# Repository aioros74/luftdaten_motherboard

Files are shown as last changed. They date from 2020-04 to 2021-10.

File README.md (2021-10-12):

# Luftdaten motherboard
## Description
### French version
La carte support luftdaten v1r1 est un circuit imprimé destiné à simplifier et apporter plus d’options au montage du détecteur de particules fines du projet Sensor Community (https://sensor.community/fr/). La page du montage: https://sensor.community/fr/sensors/airrohr/

Cette carte permet :
* D’exposer les IOs de l’ESP8266 sur des connecteurs.
* De fixer l’ESP8266 et les détecteurs de particules fines SDS011 et PMS7003 sur une même carte, et évite les câblages volants.
* D’utiliser le câble fourni avec le SDS011.
* Différentes options d’alimentation :
  * Câble USB.
  * Alimentation externe directe.
  * Alimentation externe avec régulateurs DC/DC.

### English version

The luftdaten v1r1 motherboard is a printed circuit intended to simplify and provide more options for mounting the particule matter sensors of the Sensor Community project (https://sensor.community/en/). Link to the hardware: https://sensor.community/fr/sensors/airrohr/

This card allows:
* Access to ESP8266 I/0
* To fix the ESP8266 and the particule matter sensors SDS011 and PMS7003 on the same card, and avoid flying cables.
* Use the cable provided with the SDS011.
* Several power supply options:
	* USB cable.
	* External direct power supply.
	* External power supply with DC/DC regulators.

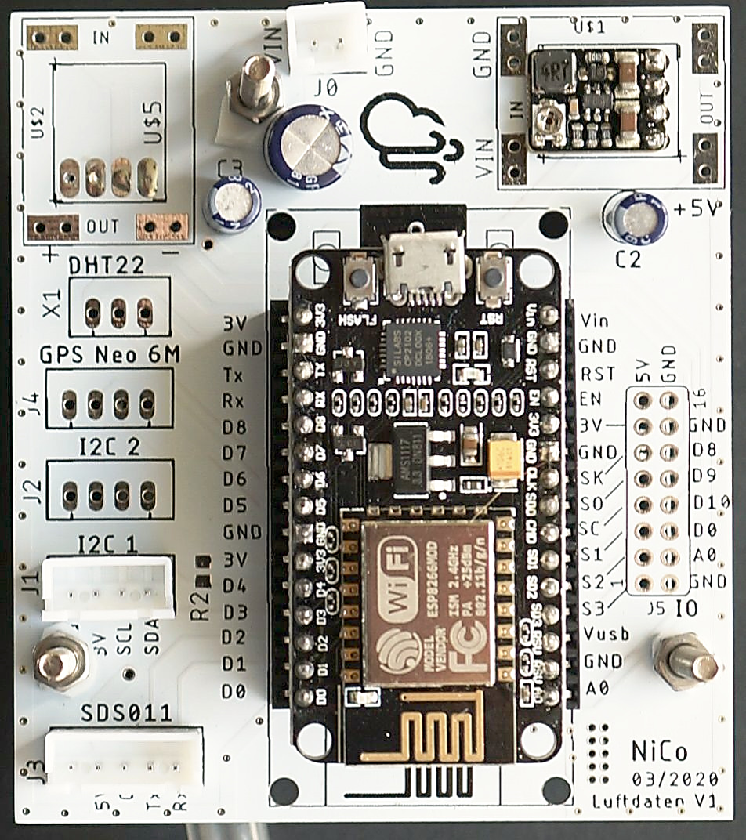
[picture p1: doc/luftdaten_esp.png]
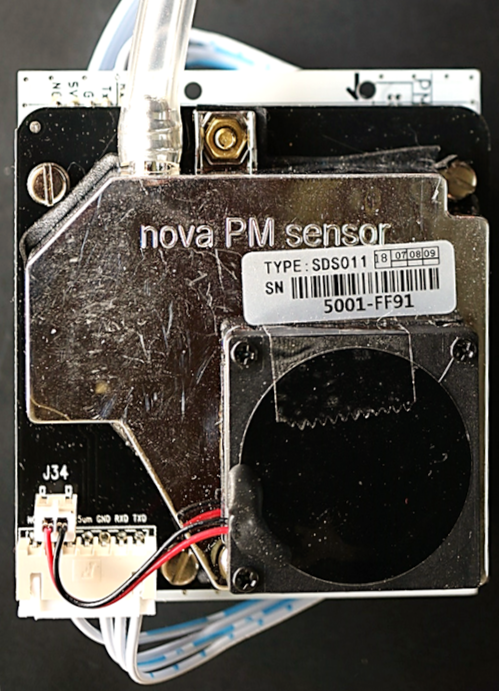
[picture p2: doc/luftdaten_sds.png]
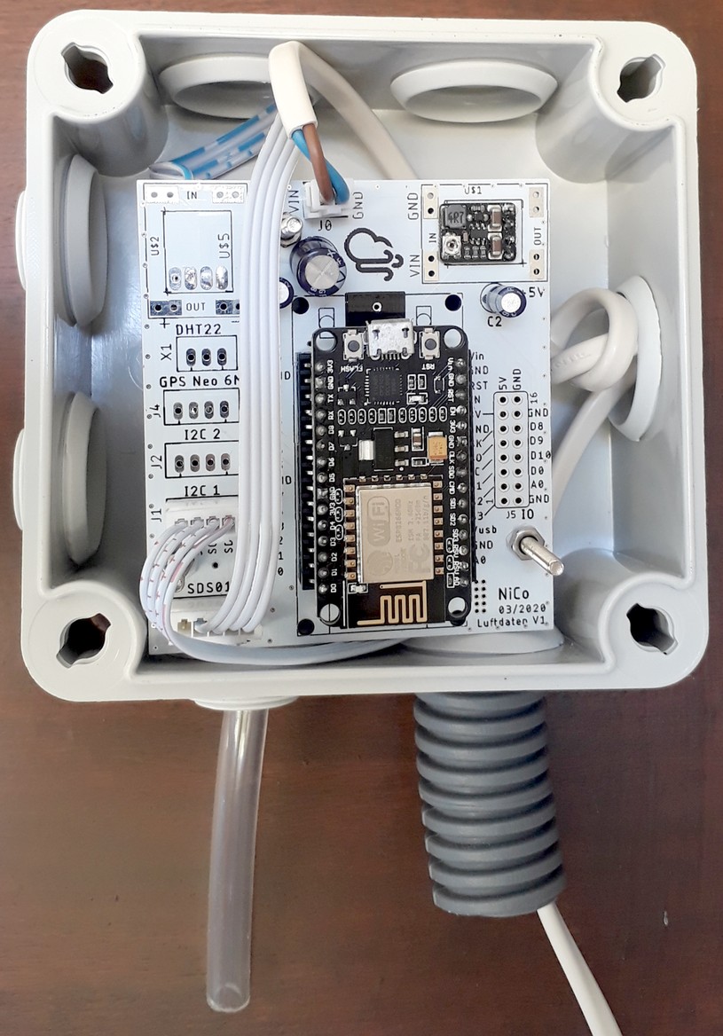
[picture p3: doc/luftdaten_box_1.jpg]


## Documentation
* Documentation de la carte: [documentation](./doc/Carte%20Support%20Luftdaten%20v1r1.pdf)
* Schéma de la carte: [schéma](./doc/schematic_uftdaten_v1r1.pdf)
* CAO Eagle: [CAO](./cao/)
* Fichiers de fabrication: [gerbers](./manufacturing/)
* Photos du PCB

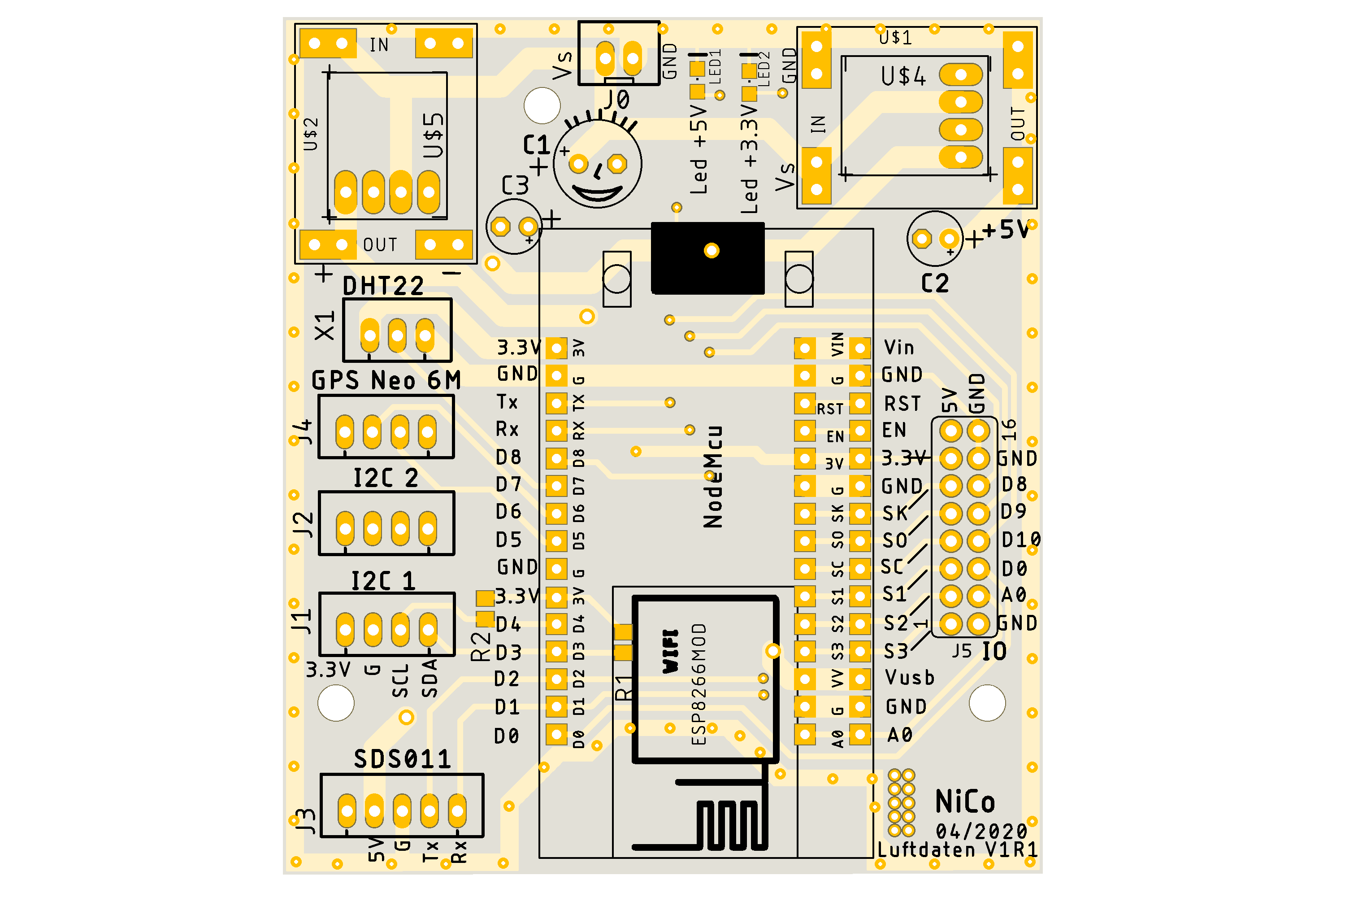
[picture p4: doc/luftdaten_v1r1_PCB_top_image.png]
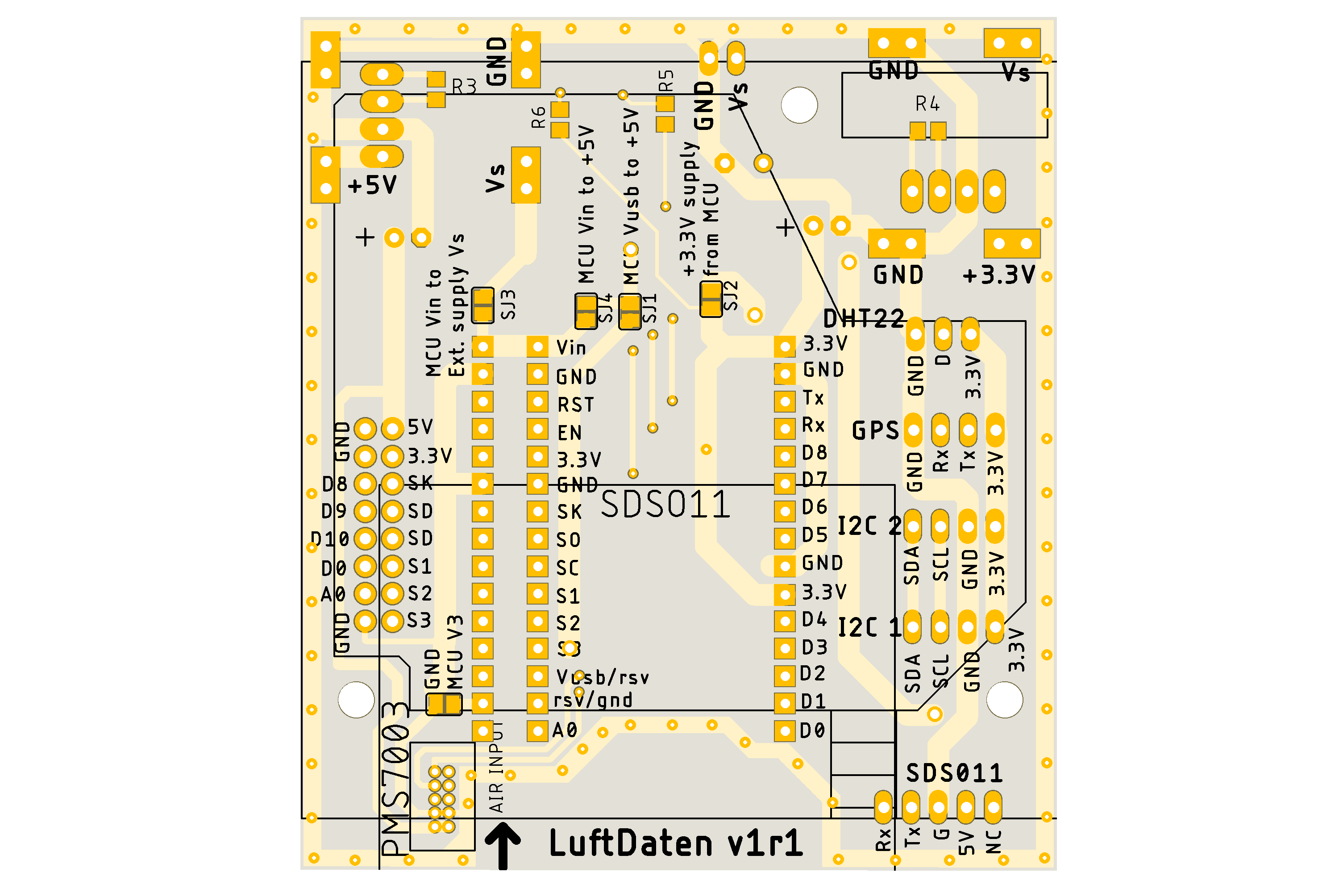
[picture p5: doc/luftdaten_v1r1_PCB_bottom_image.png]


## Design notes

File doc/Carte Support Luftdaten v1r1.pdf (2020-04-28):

# Carte Support Luftdaten

v1r1

## Nicolas Letendre

28/04/2020

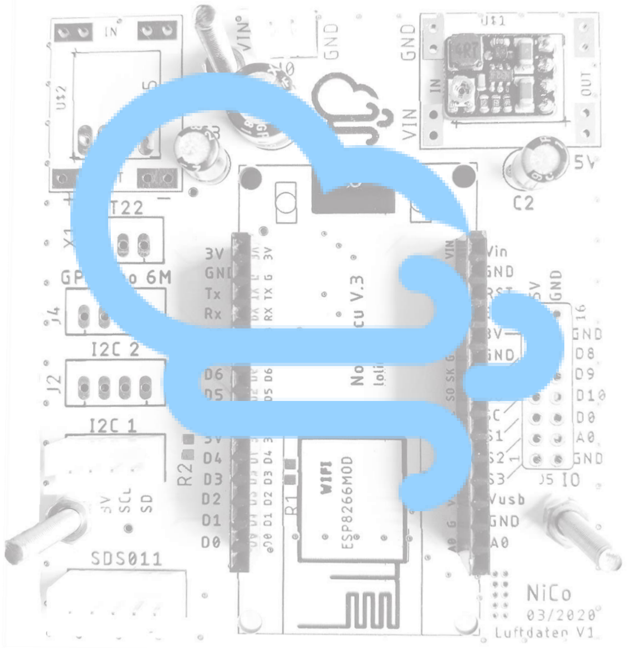
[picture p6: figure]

### Table des matières

## 1 Description

La carte support luftdaten v1r1 est un circuit imprimé destiné à simplifier et apporter plus
d’options | au | montage | du | détecteur de | particules | fines | du | projet | Luftdaten
(https://luftdaten.info/fr/accueil/).
Cette carte permet :
- D’exposer les IOs de l’ESP8266 sur des connecteurs.
- De fixer l’ESP8266 et les détecteurs de particules fines SDS011 et PMS7003 sur une même carte, et évite les câblages volants.
- D’utiliser le câble fourni avec le SDS011.
- Différentes options d’alimentation :
- Câble USB.
- Alimentation externe directe.
- Alimentation externe avec régulateurs DC/DC.

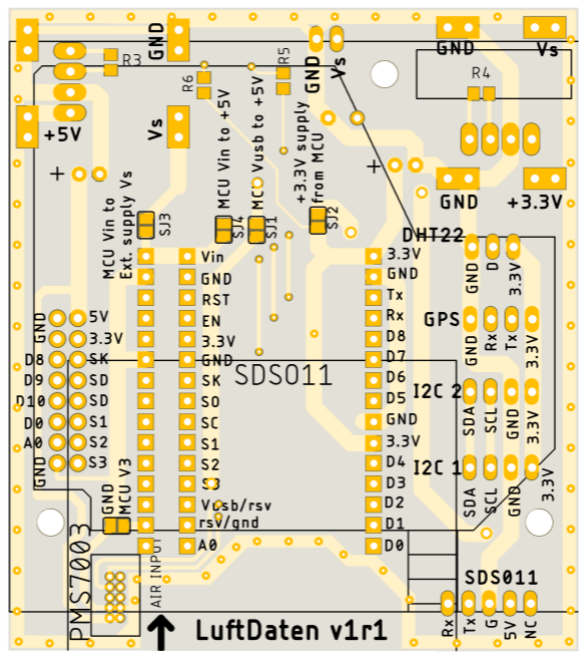
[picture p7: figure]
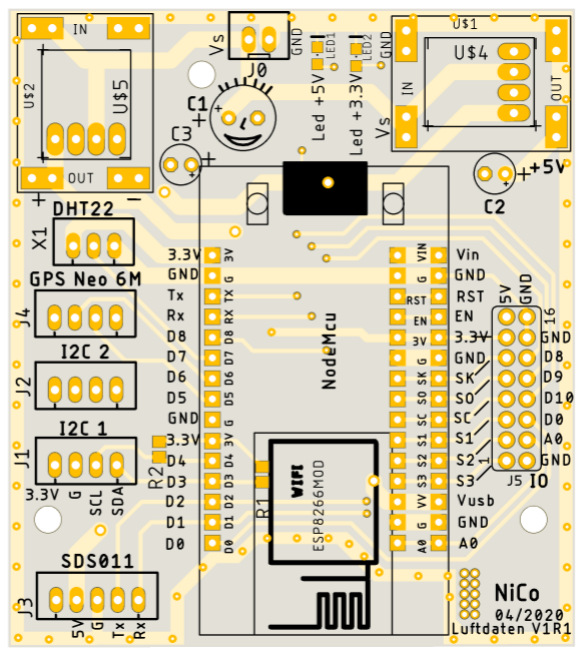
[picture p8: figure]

Figure 1: Vue de la carte support. A gauche vue de dessus, à droite vue de dessous.

## 2 Connectique

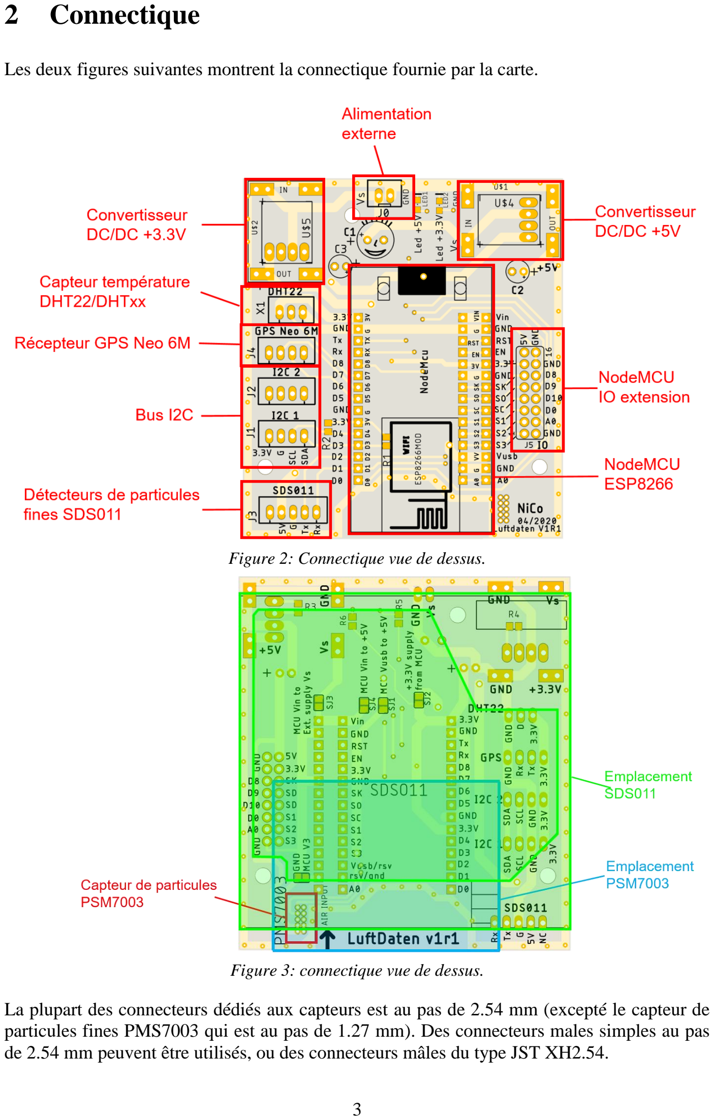
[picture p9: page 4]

Les deux figures suivantes montrent la connectique fournie par la carte.

Figure 2: Connectique vue de dessus.

Figure 3: connectique vue de dessus.

La plupart des connecteurs dédiés aux capteurs est au pas de 2.54 mm (excepté le capteur de particules fines PMS7003 qui est au pas de 1.27 mm). Des connecteurs males simples au pas de 2.54 mm peuvent être utilisés, ou des connecteurs mâles du type JST XH2.54.

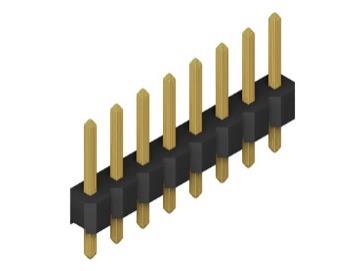
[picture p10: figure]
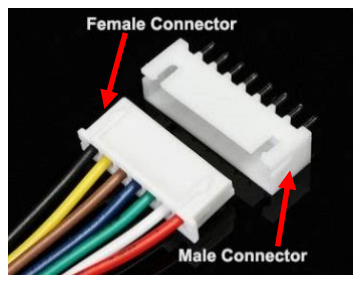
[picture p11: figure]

Broches au pas de 2.54 mm | Connecteurs JST XH2.54

### 2.1 NodeMCU ESP8266

Le cœur du montage est la carte NodeMCU V3, basée sur un contrôleur ESP8266. Deux types de NodeMCU V3 existent sur le marché :

- Une version avec un contrôleur USB CH340.
- Une version un peu moins large basée sur le contrôleur USB CP2102.

La carte support accepte les deux types de contrôleurs.

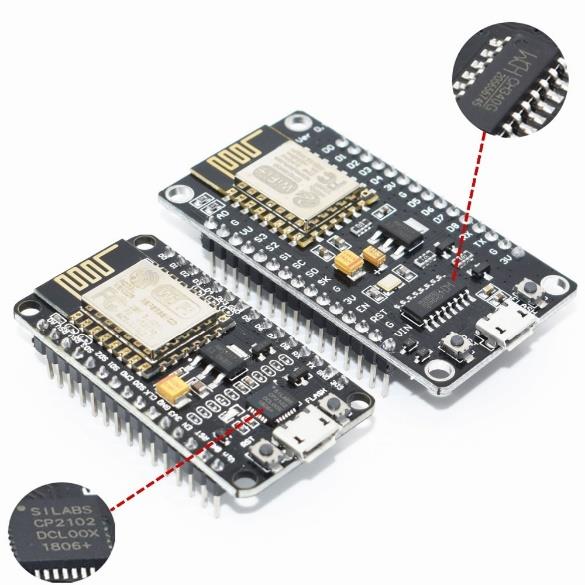
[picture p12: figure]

Figure 4: NodeMCU V3. A gauche basée sur un contrôleur CP2102 à droite sur le contrôleur CH340.

Sur la carte support, le pas des connecteurs pour le NodeMCU est de 2.54 mm. L’écart entre les deux rangées est de 22.86 mm pour la version CP2102 et de 27.94 mm pour la version CH340.

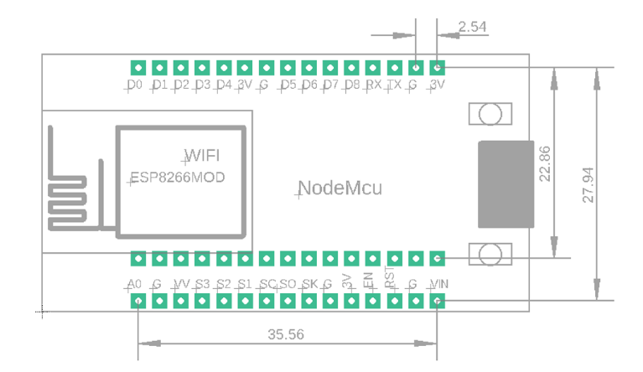
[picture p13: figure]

Figure 5: Dimension des broches du NodeMCU.

Le NodeMCU peut être soit soudé directement sur la carte support, ou soit inséré sur des supports femelles au pas de 2.54 mm soudés sur la carte. (Deux supports 1x15 au pas de 2.54 mm)

Figure 6: support femelle 1x15 au pas de 2.54 mm

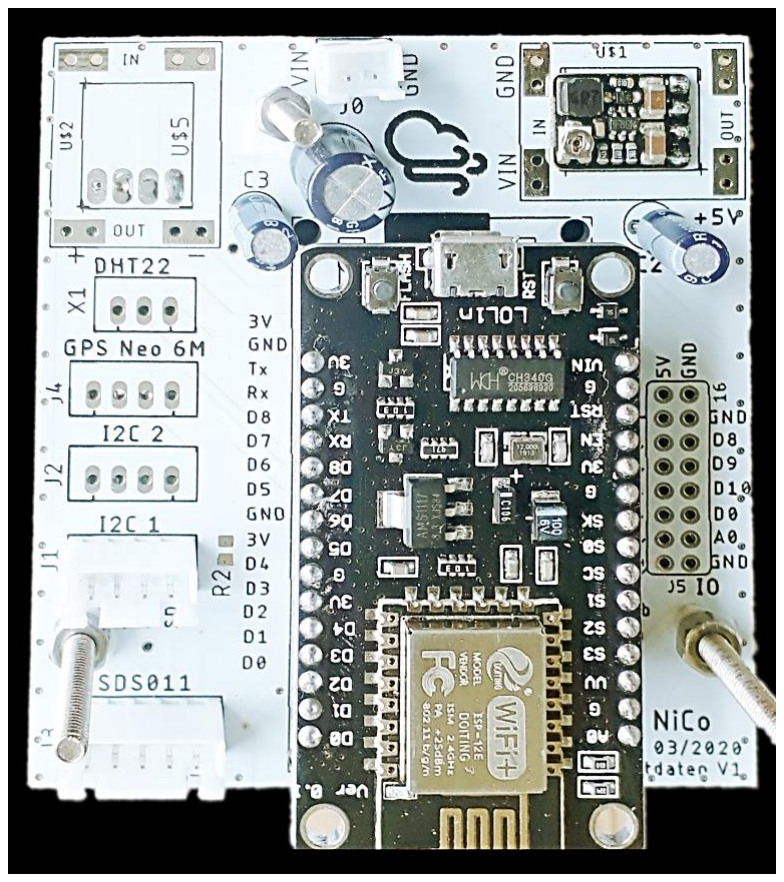
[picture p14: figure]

Figure 7 : vue de la carte support avec le NodeMCU.

### 2.2 Capteur SDS011

La carte support accepte le capteur de particules fine SDS011 de Inovafitness. Ce capteur se monte sur la face « dessous » de la carte support.
ATTENTION : Le capteur ne doit pas toucher le circuit imprimé pour ne pas mettre en court-circuit les broches du NodeMCU soudé sur l’autre face. Il est donc conseillé de monter le SDS011 avec des entretoises, ou d’insérer un isolant (plastique ou autre) entre le SDS011 et le circuit imprimé.

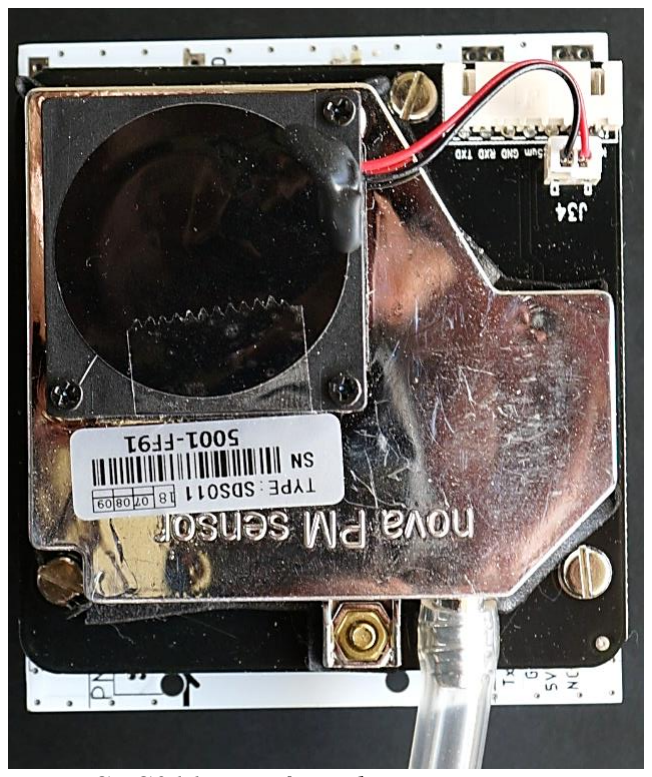
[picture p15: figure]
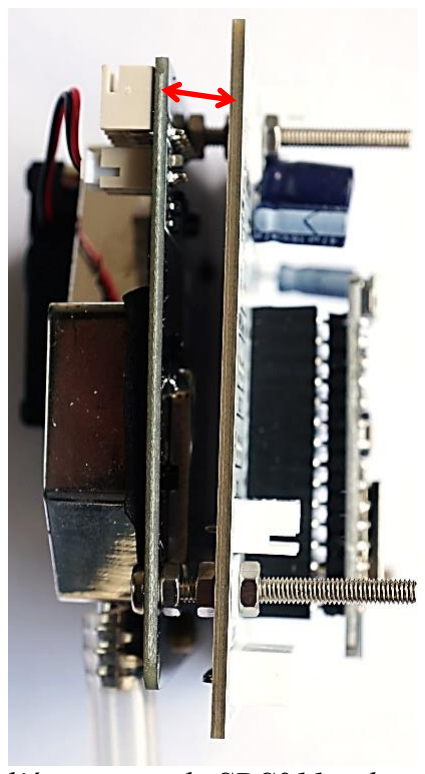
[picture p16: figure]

Figure 8 : SDS011 monté sur la carte support. Notez l’écart entre le SDS011 et la carte.

Le SDS011 se connecte sur le connecteur J3 sur la face « dessus » de la carte support avec la nappe de fils livrée avec le SDS011. Sur la carte support les broches du capteur de particules fines sont reliées au NodeMCU comme indiqué dans le tableau suivant :

SDS011 | Connecteur carte support
Pin 3 : 5V | 5V
Pin 5 : GND | GND
Pin 6 : R | Tx – NodeMCU pin D2
Pin 7 : T | Rx – NodeMCU pin D1
Table 1 : Table de correspondances entre les broches du SDS011 et la carte support.

### 2.3 Capteur PMS7003

Le capteur de particules fines PMS7003 est un autre capteur qui peut être monté directement sur la carte support. Le capteur se monte sur la face « dessous » de la carte support. Il est nécessaire de souder la connecteur 2x5 (2 rangées de 5 broches) au pas de 1.27mm. Ce connecteur est parfois vendu avec le PMS7003.
ATTENTION : Le PMS7003 doit être fixé sur la carte support avec du scotch double face par exemple. Ce double face joue aussi le rôle d’isolant électrique entre le circuit imprimé et le capteur, notamment si la pellicule de protection bleue du PSM7003 a été retirés. Le capot du PMS7003 étant métallique, il pourrait provoquer des court-circuits sur la carte support. De plus, il est nécessaire de souder le NodeMCU sans que les broches dépassent sur la face « dessous » de la carte support.

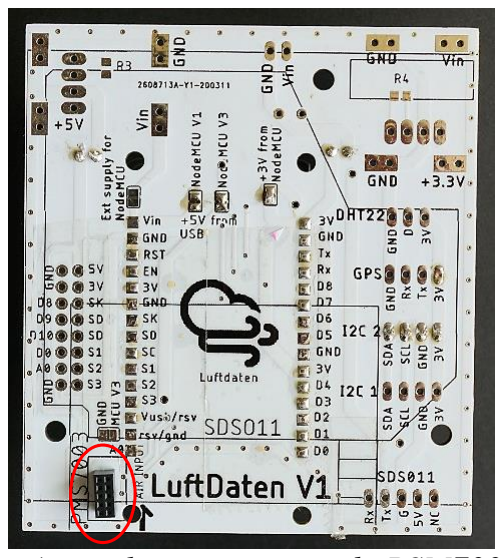
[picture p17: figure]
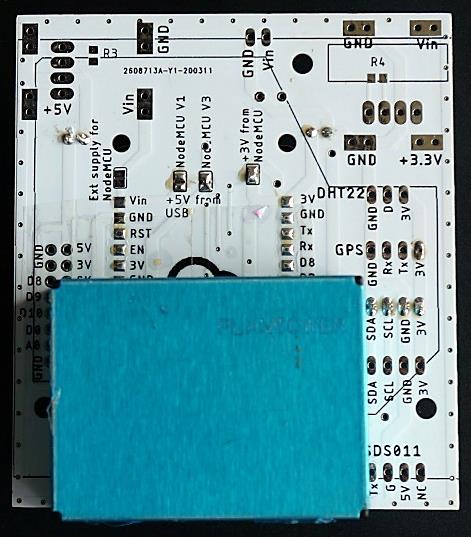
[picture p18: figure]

Figure 9 : A gauche : connecteur du PSM7003 soudé sur la carte. A droite : capteur monté.

PMS7003 | Node MCU
Pin 1 : 5V | +5V
Pin 2 : 5V | +5V
Pin 3 : GND | GND
Pin 4 : GND | GND
Pin 5 : Reset | NC
Pin 6 : NC (Not Connected) | NC
Pin 7 : RX | D2
Pin 8 : NC | NC
Pin 9 : TX | D1
Pin 10 : Set | NC
Table 2 : Table de correspondance entre les broches du PMS7003 et la carte support.

### 2.4 Capteur de température et d’humidité DHT22

Le capteur de température DHT22 se branche sur le connecteur X1.

DHT22 | Carte support

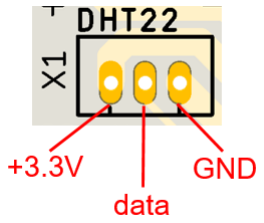
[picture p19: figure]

Pin 1 : VCC | +3.3V
Pin 2 : DATA | D – NodeMCU pin D7
Pin 3 : NC | -
Pin 4 : GND | GND
Table 3 : Table de correspondance entre les broches du DHT22 et la carte support.

### 2.5 GPS Neo-6m

Un récepteur GPS de type Neo-6m peut être connecté à la carte support sur le connecteur J4. Le récepteur Neo-6m est généralement vendu sous forme de module. Ce module communique avec le NodeMCU à travers une liaison série.

Module Neo-6m | Carte support connecteur J4

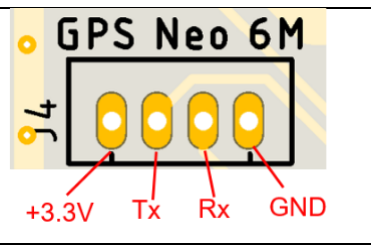
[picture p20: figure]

Pin VCC | +3.3V
Pin RX | Tx – Node MCU pin D6
Pin TX | Rx è Node MCU pin D5
Pin GND | GND

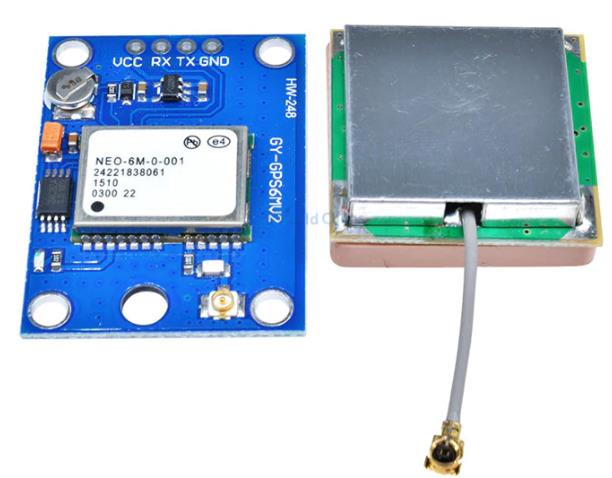
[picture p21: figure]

Table 4: Table de correspondance entre les broches du module Neo-6m et la carte support.

### 2.6 I2C

La carte support possède deux connecteurs I2C nommés J1 et J2. Le projet Luftdaten prend en compte un certain nombre de modules I2C dont voici une liste non exhaustive :

- Capteurs de température et d’humidité : BME280 / HTU21D / SHT3x.
- Capteurs de température et de pression : BMP180.
- Capteur de température, humidité, pression : BMP280.
- Ecrans OLED basés sur le contrôleur SH1106 ou SSD1306.

Les broches I2C (SDA et SCL) sont reliées aux broches D3 et D4 du NodeMCU.

Carte support J1 et J2

+3.3V
GND
SCL – NodeMCU pin D4
SDA – NodeMCU pin D3
Table 5 : Brochage des connecteurs I2C.

Les résistance R1 et R2 permettent d’ajouter des résistances de tirage (pull-up) externes sur les lignes du bus I2C (SDA et SCL).

### 2.7 NodeMCU I/O

Le connecteur J5 permet un accès à toutes les broches du NodeMCU non utilisées pas les autres connecteurs. Le tableau suivant montre le brochage du connecteur J5.

Carte support J5

Pin 1 : NodeMCU pin S3 | Pin 2 : GND
Pin 3 : NodeMCU pin S2 | Pin 4 : NodeMCU pin A0
Pin 5 : NodeMCU pin S1 | Pin 6 : NodeMCU pin D0
Pin 7 : NodeMCU pin SC | Pin 8 : NodeMCU pin D10
Pin 9 : NodeMCU pin SD | Pin 10 : NodeMCU pin D9
Pin 11 : NodeMCU pin SK | Pin 12 : NodeMCU pin D10
Pin 13 :+3.3V | Pin 14 : GND
Pin 15 :+5V | Pin 16 : GND
Table 6 : Brochage du connecteur d’extension des I0s du NodeMCU.

## 3 Alimentation

Pour fonctionner le système à besoins d’une alimentation +3.3V pour le NodeMCU et certains capteurs, et d’une alimentation +5V pour les capteurs de particules fines.
La carte support offre plusieurs possibilités pour fournir ces alimentations. Des ponts de soudure permettent de sélectionner un profil d’alimentation parmi les différentes options.

### 3.1 Alimenter le NodeMCU V3

La figure suivante montre le schéma de l’alimentation du NodeMCU V3.

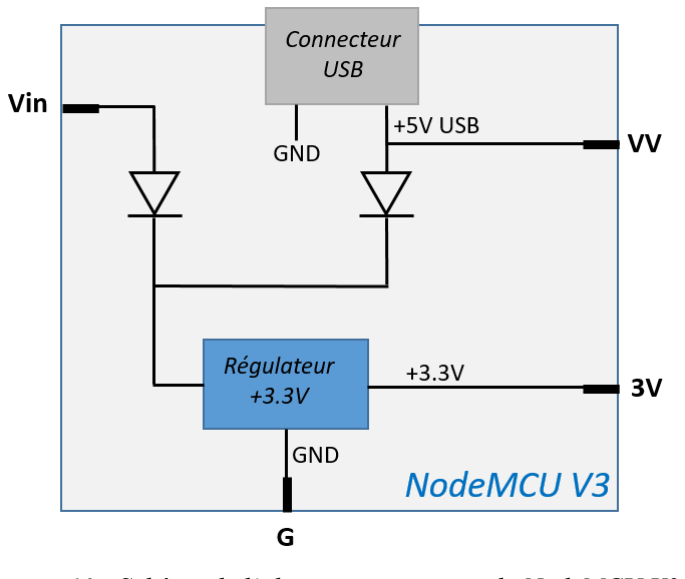
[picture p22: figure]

Figure 10 : Schéma de l’alimentation interne du NodeMCU V3.

Il y a 3 façons d’alimenter le nodeMCU :

1. Par le connecteur USB. Le bus USB fourni une alimentation de +5V. Le régulateur linéaire AMS1117-3.3 se charge alors de convertir ce +5V en +3.3V. Le NodeMCU fourni donc le +5V sur sa broche VV, et le +3.3V sur sa broche 3V.
2. Par la broche Vin. La tension sur la broche Vin doit être comprise entre +4.8V (= 3.3V+Vdrop+Vdiode = 3.3+1.3+0.2) et +15V. Dans cette configuration, le NodeMCU fourni le +3.3V sur sa broche 3V. Par contre, il ne produit pas de +5V.
3. Par la broche 3.3V. Dans cette configuration, le NodeMCU est alimenté directement par un +3.3V externe appliqué sur la broche 3V. Le nodeMCU ne fournit pas de +5V.

### 3.2 Les options d’alimentation de la carte support

### 3.2.1 Le connecteur d’alimentation

La carte support possède un connecteur d’alimentation J0 qui permet de brancher une alimentation externe. Ce connecteur doit être au pas de 2.54 mm. Il y a la possibilité d’ajouter un condensateur C1 pour filtrer l’alimentation.

### 3.2.2 Convertisseurs DC/DC

La carte support possède deux emplacements pour des convertisseurs DC/DC ; un pour produire une tension de +5V, et l’autre pour le +3.3V. Un régulateur DC/DC possède un rendement supérieur à un régulateur linéaire. Il peut y avoir plusieurs raisons d’utiliser un régulateur DC/DC :

- Augmenter la plage d’alimentation du montage jusqu’à +28V, et donc utiliser n’importe quelle « bloc mural » AC/DC. Si la connexion entre le bloc mural et le montage Luftdaten, il peut y avoir une perte de tension dans les longs fils. Alimenter le montage avec une tension plus élevée puis régulée avec une convertisseur DC/DC supprime cet inconvénient.
- Améliorer le rendement de conversion.

Deux régulateurs DC/DC peuvent être utilisés sur la carte support :

Module basé sur le MP1584 | Module BB2359

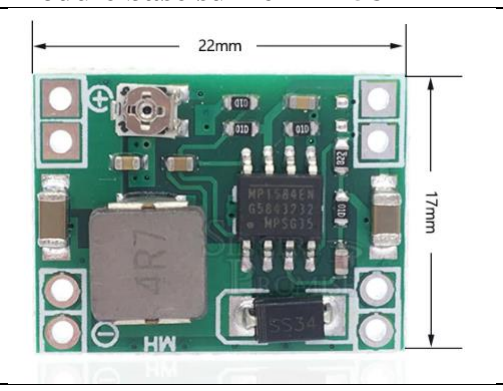
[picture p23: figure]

régulateur | MP1584EN | MP2359
Tension d’entrée | +4.5V à +28V | +4.5V à +24V
Tension de sortie | +0.8V à +25V | +0.81V à +15V
Courant max | 3A | 1.2A
Table 7 : Les deux régulateurs DC/DC utilisables sur la carte support.

### 3.2.3 Schéma d’alimentation de la carte support

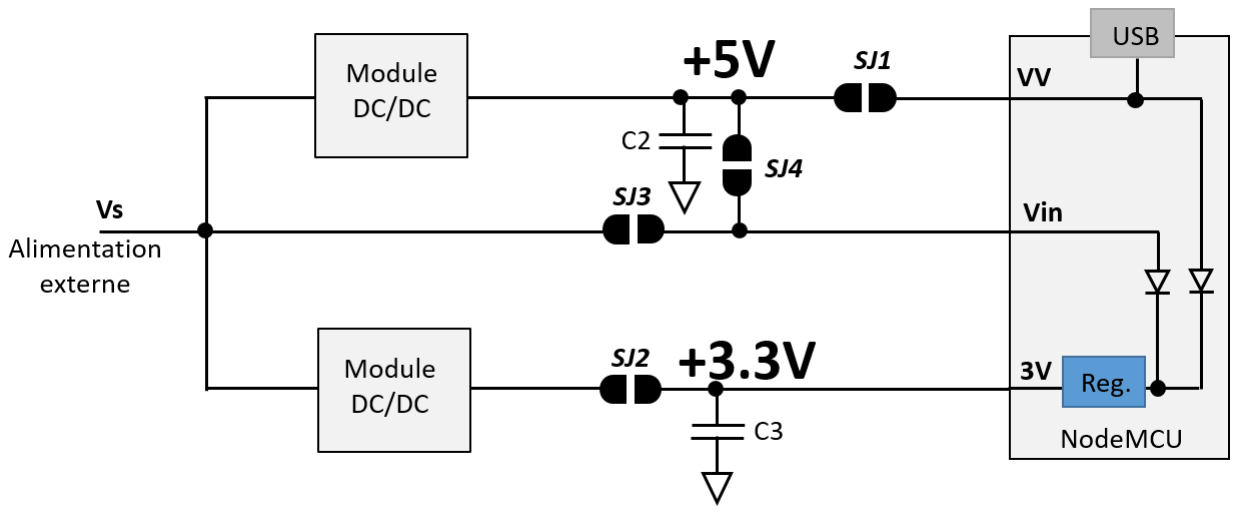
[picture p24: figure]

Figure 11 : Schéma général des alimentations sur la carte support.

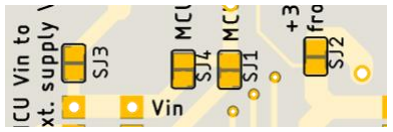
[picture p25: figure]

Figure 12: Ponts SJ1 à SJ4.

Quatre ponts (SJ1 à SJ4) permettent de choisir l’option d’alimentation. Une goutte de soudure sur le pont permet de réaliser la connexion. Les condensateurs C2 et C3 permettent de filtrer les rails
d’alimentation | (resp. | +5V | et | +3.3V). | Ces
condensateurs ne sont pas obligatoires.

Alimentation par l’USB

Le montage peut être alimenté directement par le connecteur USB du NodeMCU. Le tableau suivant montre la configuration nécessaire. Une croix signifie que le pont doit être soudé.

Dans cette configuration, les régulateurs DC/DC ne sont pas câblés et l’alimentation externe n’est pas utilisée.

SJ1 | X

SJ2

SJ3

SJ4

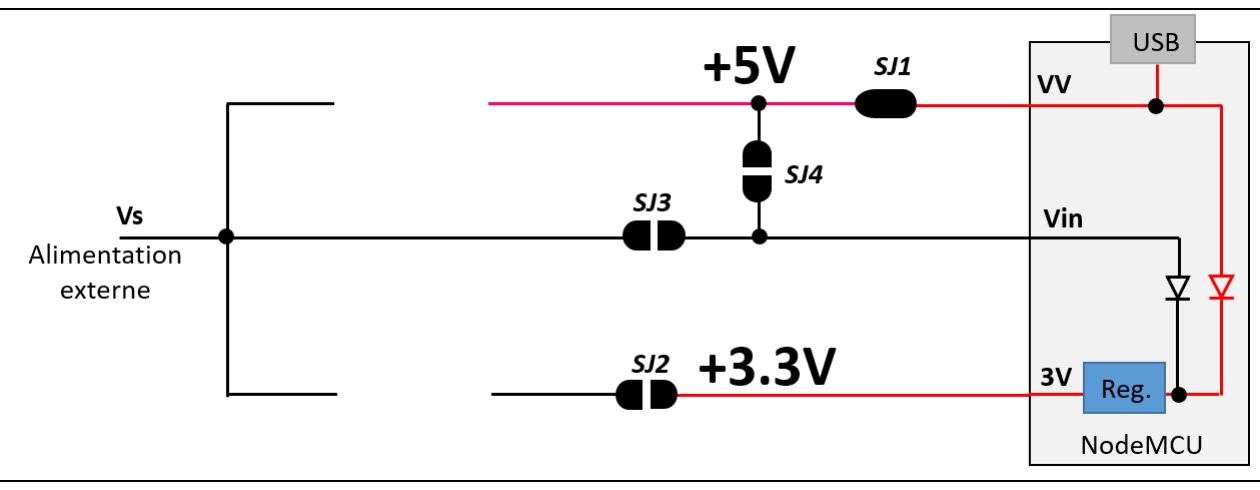
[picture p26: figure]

Figure 13 : Configuration pour une alimentation par câble USB.

Alimentation externe +5V

Le montage est alimenté par une alimentation externe +5V. Les convertisseurs DC/DC ne sont pas utilisés.

SJ1

SJ2

SJ3 | X
SJ4 | X

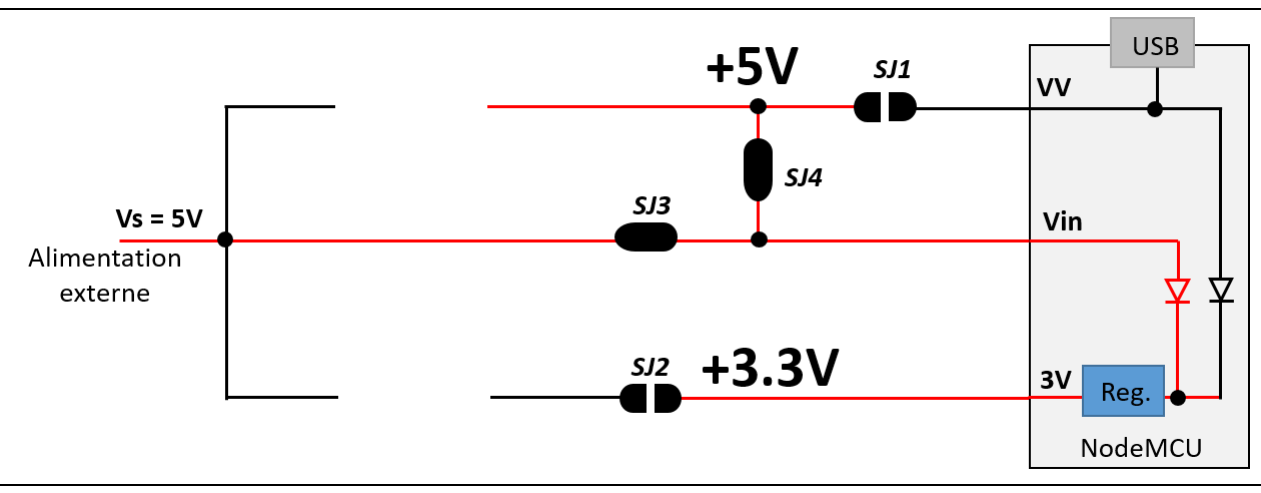
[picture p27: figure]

Figure 14 : Configuration pour une alimentation par un +5V externe.

Alimentation externe >5V – régulateur DC/DC +5V

Dans cette configuration, le montage est alimenté par une alimentation externe supérieure à 5V. Le +5V est fourni par le convertisseur DC/DC, et le +3.3V par le nodeMCU.

SJ1

SJ2

SJ3

SJ4 | X

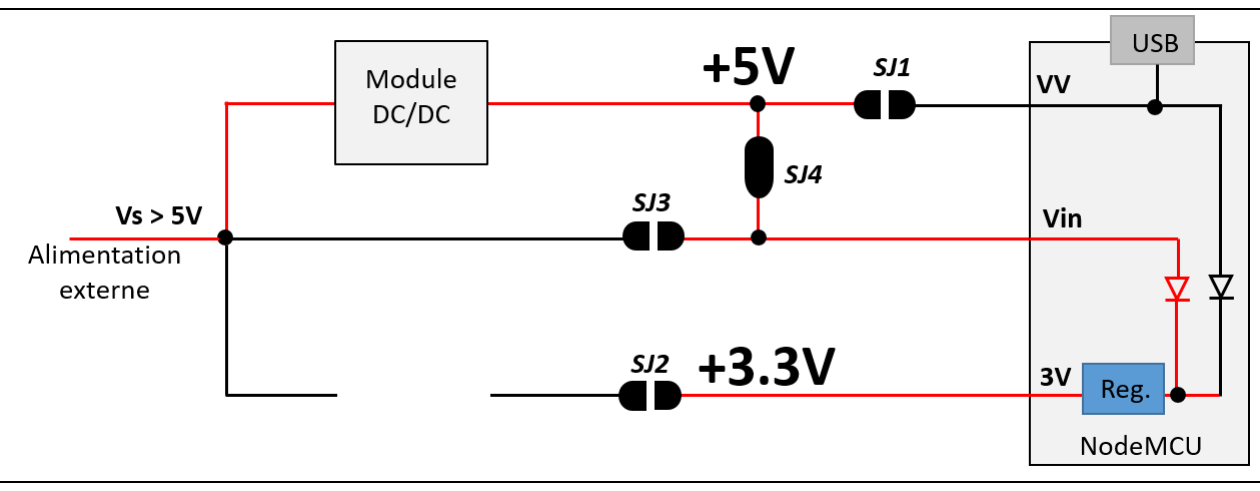
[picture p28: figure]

Figure 15 : Configuration pour une alimentation par une tension externe supérieure à 5V.

Alimentation externe >5V – régulateurs DC/DC +5V et +3.3V

Dans cette configuration, le montage est alimenté par une alimentation externe supérieure à 5V. Le +5V est fourni par le convertisseur DC/DC, et le +3.3V par le second régulateur DC/DC.

SJ1

SJ2 | X

SJ3

SJ4

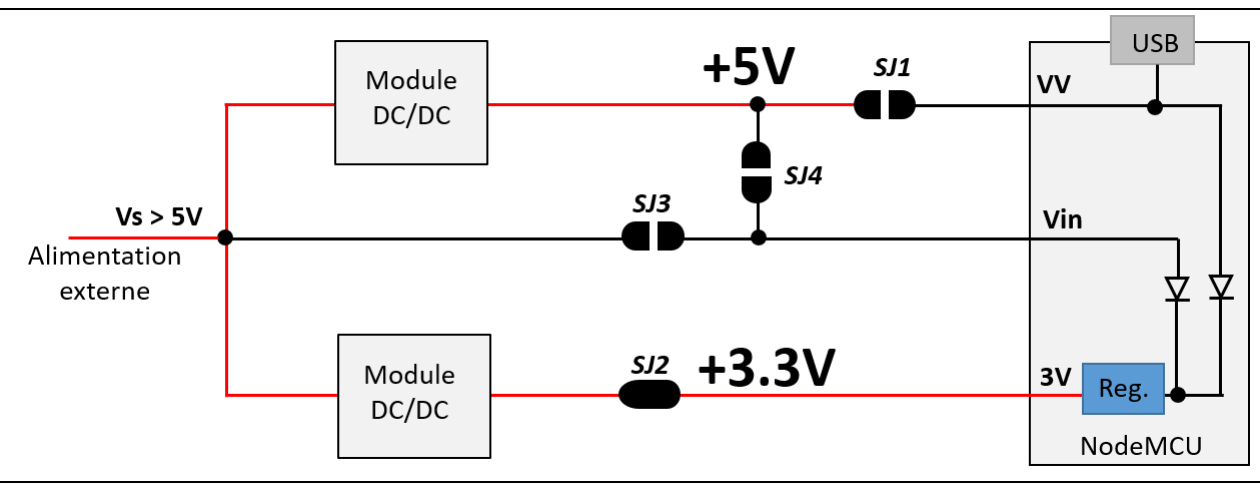
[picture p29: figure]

Figure 16 : Configuration pour une alimentation par une tension externe supérieure à 5V.

### 3.2.4 Leds

Il est possible de câbler des leds sur les rails d’alimentation +5V et +3.3V. Ces leds ainsi que les résistances associées sont en format de boitier 0805.

- Pour la led +5V : cabler la led L1 et la résistance R5.
- Pour la led +3.3V : cabler la led L2 et la résistance R6.

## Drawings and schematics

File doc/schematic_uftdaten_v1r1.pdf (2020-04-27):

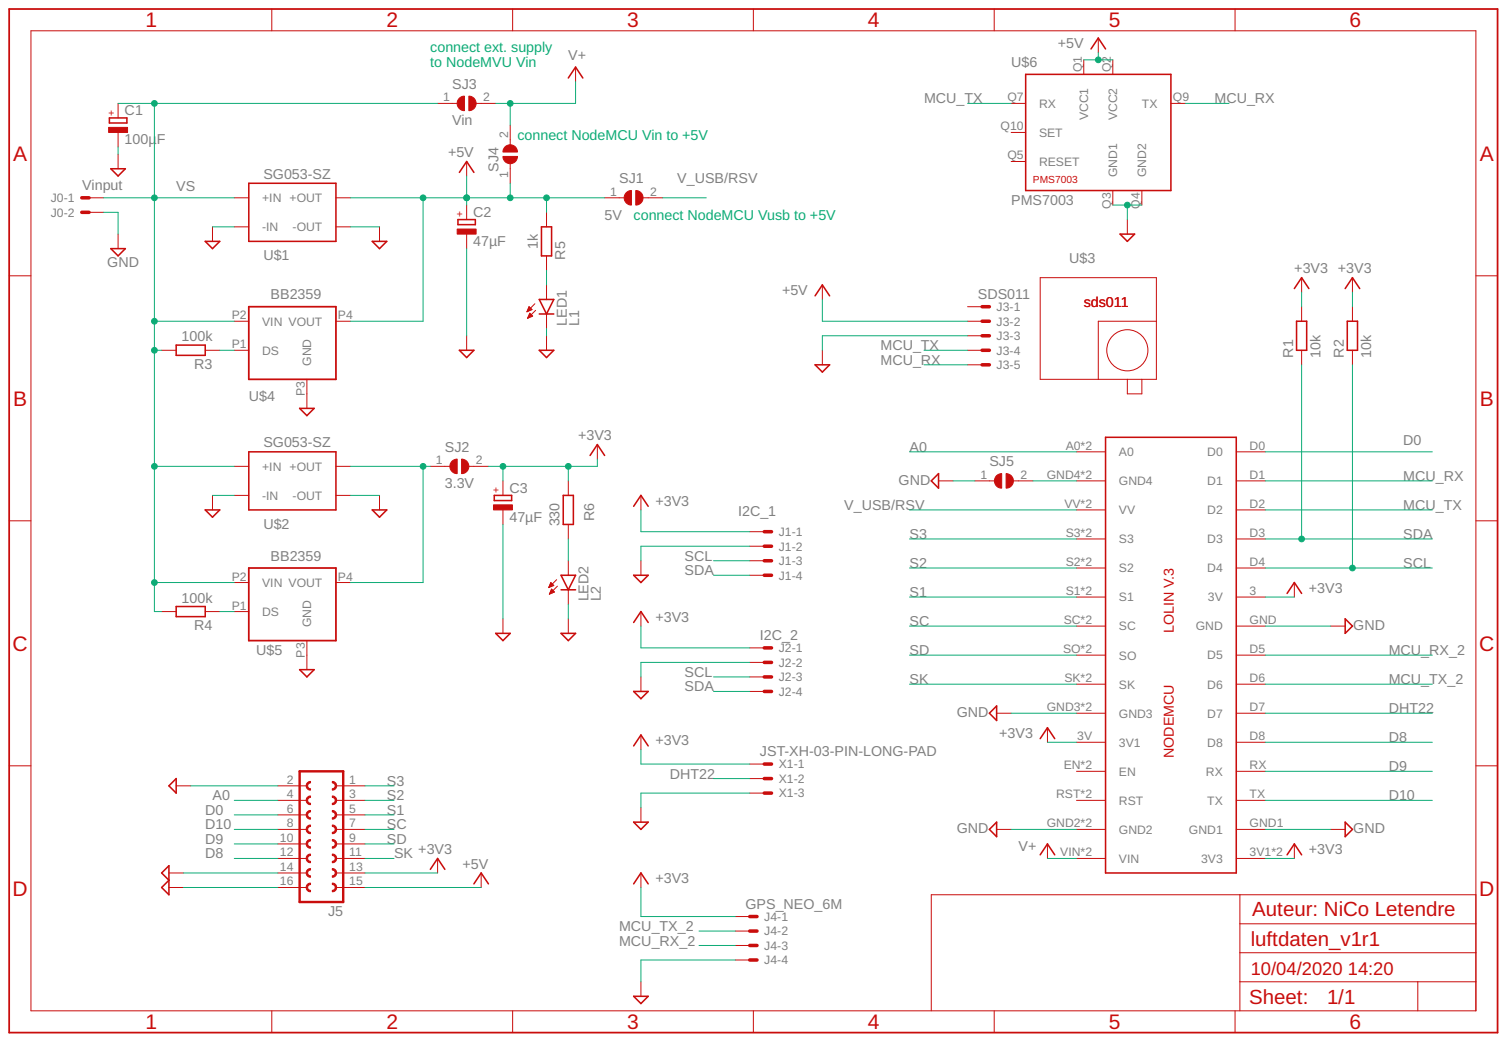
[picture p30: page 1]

connect NodeMCU Vin to +5V

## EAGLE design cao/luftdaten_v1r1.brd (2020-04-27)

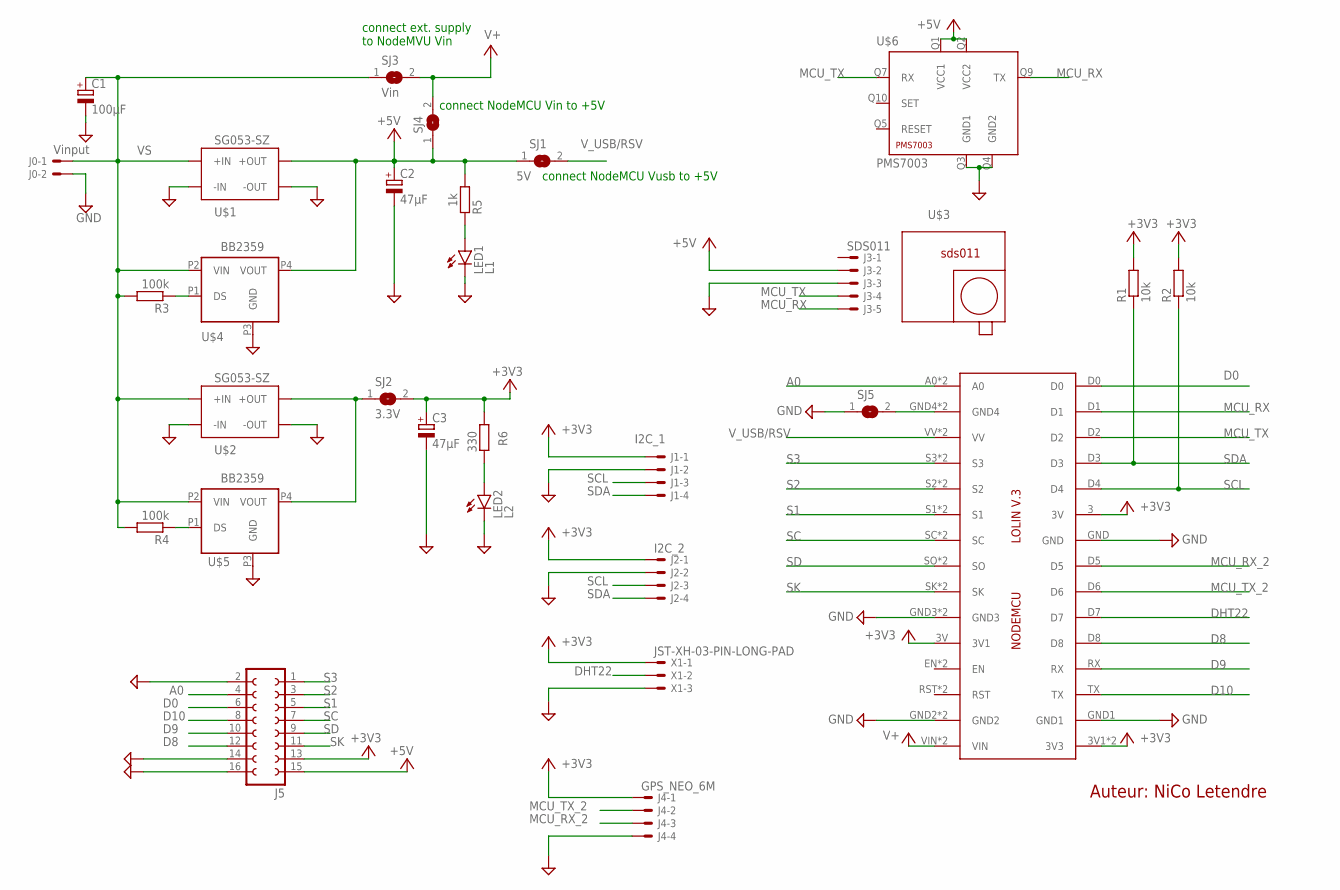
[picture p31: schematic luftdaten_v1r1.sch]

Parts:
C1: 100µF; E3,5-8
C2, C3: 47µF; E2,5-5
IC2: NodeMCU; LOLINV3
J0: Vinput; JST-XH-02-PACKAGE-LONG-PAD
J1: I2C_1; JST-XH-04-PACKAGE-LONG-PAD
J2: I2C_2; JST-XH-04-PACKAGE-LONG-PAD
J3: SDS011; JST-XH-05-PACKAGE-LONG-PAD
J4: GPS_NEO_6M; JST-XH-04-PACKAGE-LONG-PAD
J5: FE08-2
LED1: L1; CHIPLED_0805
LED2: L2; CHIPLED_0805
R1, R2: 10k; R0805
R3, R4: 100k; R0805
R5: 1k; R0805
R6: 330; R0805
SJ1: 5V; SJ
SJ2: 3.3V; SJ
SJ3: Vin; SJ
SJ4, SJ5: SJ
U$1, U$2: SG053-SZ
U$3: SDSO11; SDS011
U$4, U$5: BB2359
U$6: PMS7003
X1: JST-XH-03-PIN-LONG-PAD; JST-XH-03-PACKAGE-LONG-PAD

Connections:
+3V3: C3.+, IC2.3 (3V), IC2.3V (3V1), IC2.3V1 (3V3), IC2.3V3, J1.1, J2.1, J4.1, J5.13, R1.2, R2.2, R6.1, SJ2.2, X1.1
+5V: C2.+, J3.2, J5.15, R5.1, SJ1.1, SJ4.1, U$1.P$5 (+OUT), U$1.P$6 (+OUT), U$4.P4 (VOUT), U$6.Q1 (VCC1), U$6.Q2 (VCC2)
A0: IC2.A0, IC2.A1 (A0), J5.4
D0: IC2.D0, J5.6
D8: IC2.D8, J5.12
D9: IC2.RX, J5.10
D10: IC2.TX, J5.8
DHT22: IC2.D7, X1.2
GND: C1.-, C2.-, C3.-, IC2.GND, IC2.GND1, IC2.GND2, IC2.GND3, IC2.GND5 (GND2), IC2.GND6 (GND3), J0.2, J1.2, J2.2, J3.3, J4.4, J5.2, J5.14, J5.16, LED1.C, LED2.C, SJ5.1, U$1.P$1 (-IN), U$1.P$2 (-IN), U$1.P$7 (-OUT), U$1.P$8 (-OUT), U$2.P$1 (-IN), U$2.P$2 (-IN), U$2.P$7 (-OUT), U$2.P$8 (-OUT), U$4.P3 (GND), U$5.P3 (GND), U$6.Q3 (GND1), U$6.Q4 (GND2), X1.3
MCU_RX: IC2.D1, J3.5, U$6.Q9 (TX)
MCU_RX_2: IC2.D5, J4.3
MCU_TX: IC2.D2, J3.4, U$6.Q7 (RX)
MCU_TX_2: IC2.D6, J4.2
unnamed: IC2.GND4, IC2.GND7 (GND4), SJ5.2
unnamed: SJ2.1, U$2.P$5 (+OUT), U$2.P$6 (+OUT), U$5.P4 (VOUT)
unnamed: R3.1, U$4.P1 (DS)
unnamed: R4.1, U$5.P1 (DS)
unnamed: LED1.A, R5.2
unnamed: LED2.A, R6.2
S1: IC2.S1, IC2.S4 (S1), J5.5
S2: IC2.S2, IC2.S5 (S2), J5.3
S3: IC2.S3, IC2.S6 (S3), J5.1
SC: IC2.SC, IC2.SC1 (SC), J5.7
SCL: IC2.D4, J1.3, J2.3, R2.1
SD: IC2.SO, IC2.SO1 (SO), J5.9
SDA: IC2.D3, J1.4, J2.4, R1.1
SK: IC2.SK, IC2.SK1 (SK), J5.11
V+: IC2.VIN, IC2.VIN1 (VIN), SJ3.2, SJ4.2
VS: C1.+, J0.1, R3.2, R4.2, SJ3.1, U$1.P$3 (+IN), U$1.P$4 (+IN), U$2.P$3 (+IN), U$2.P$4 (+IN), U$4.P2 (VIN), U$5.P2 (VIN)
V_USB/RSV: IC2.VV, IC2.VV1 (VV), SJ1.2

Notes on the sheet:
connect NodeMCU Vusb to +5V
connect ext. supply to NodeMVU Vin
connect NodeMCU Vin to +5V
Auteur: NiCo Letendre

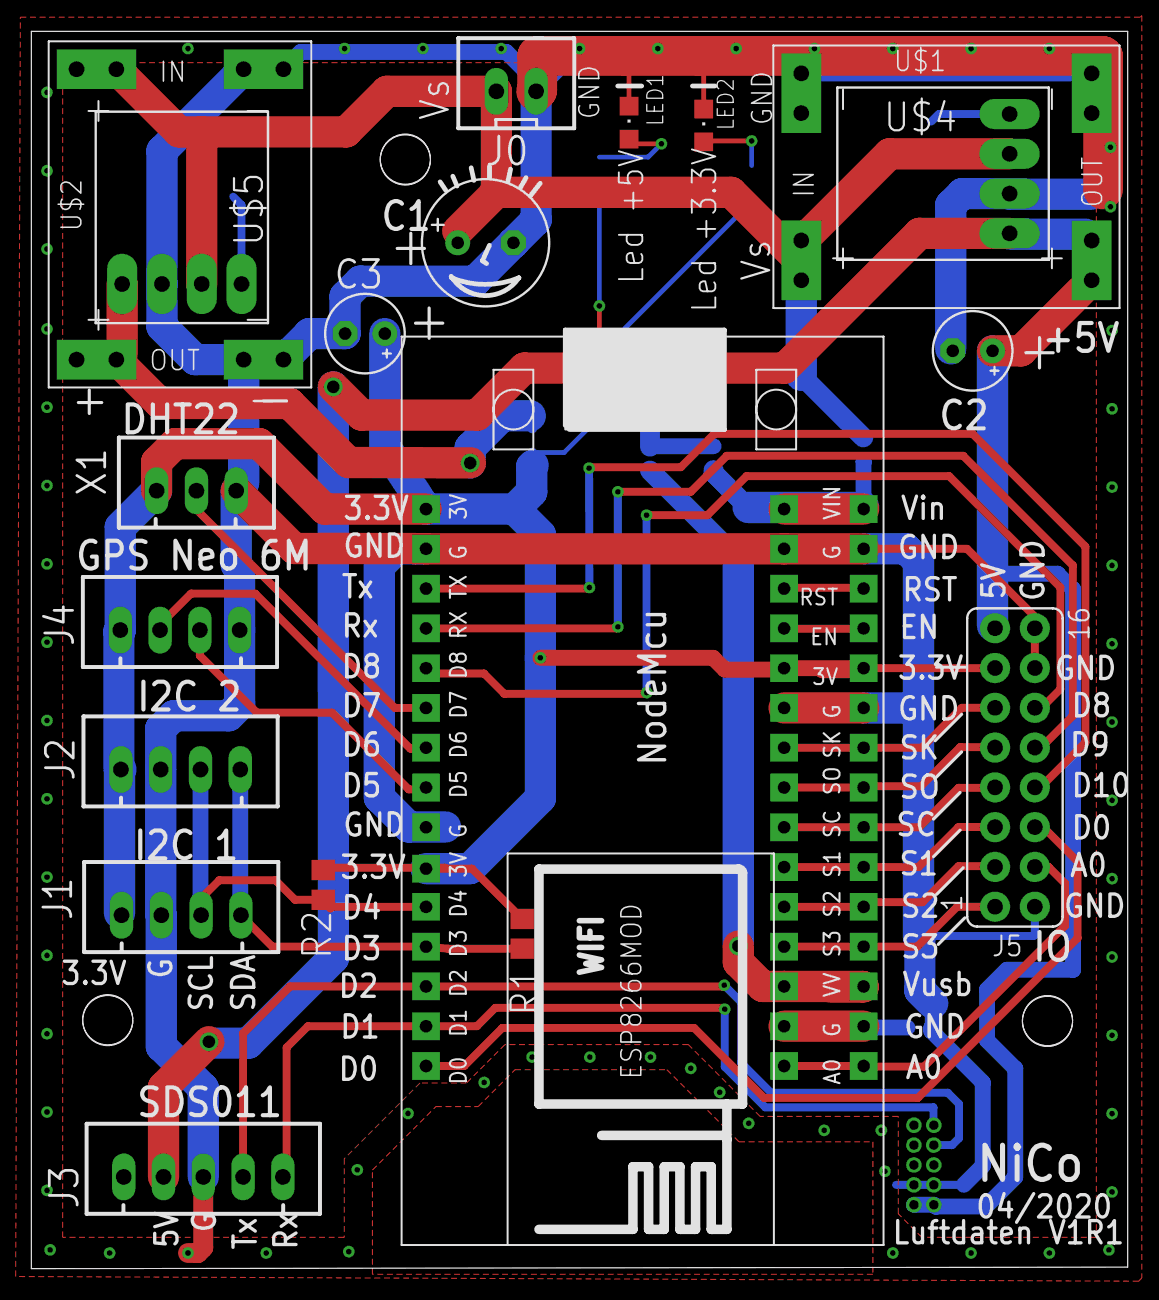
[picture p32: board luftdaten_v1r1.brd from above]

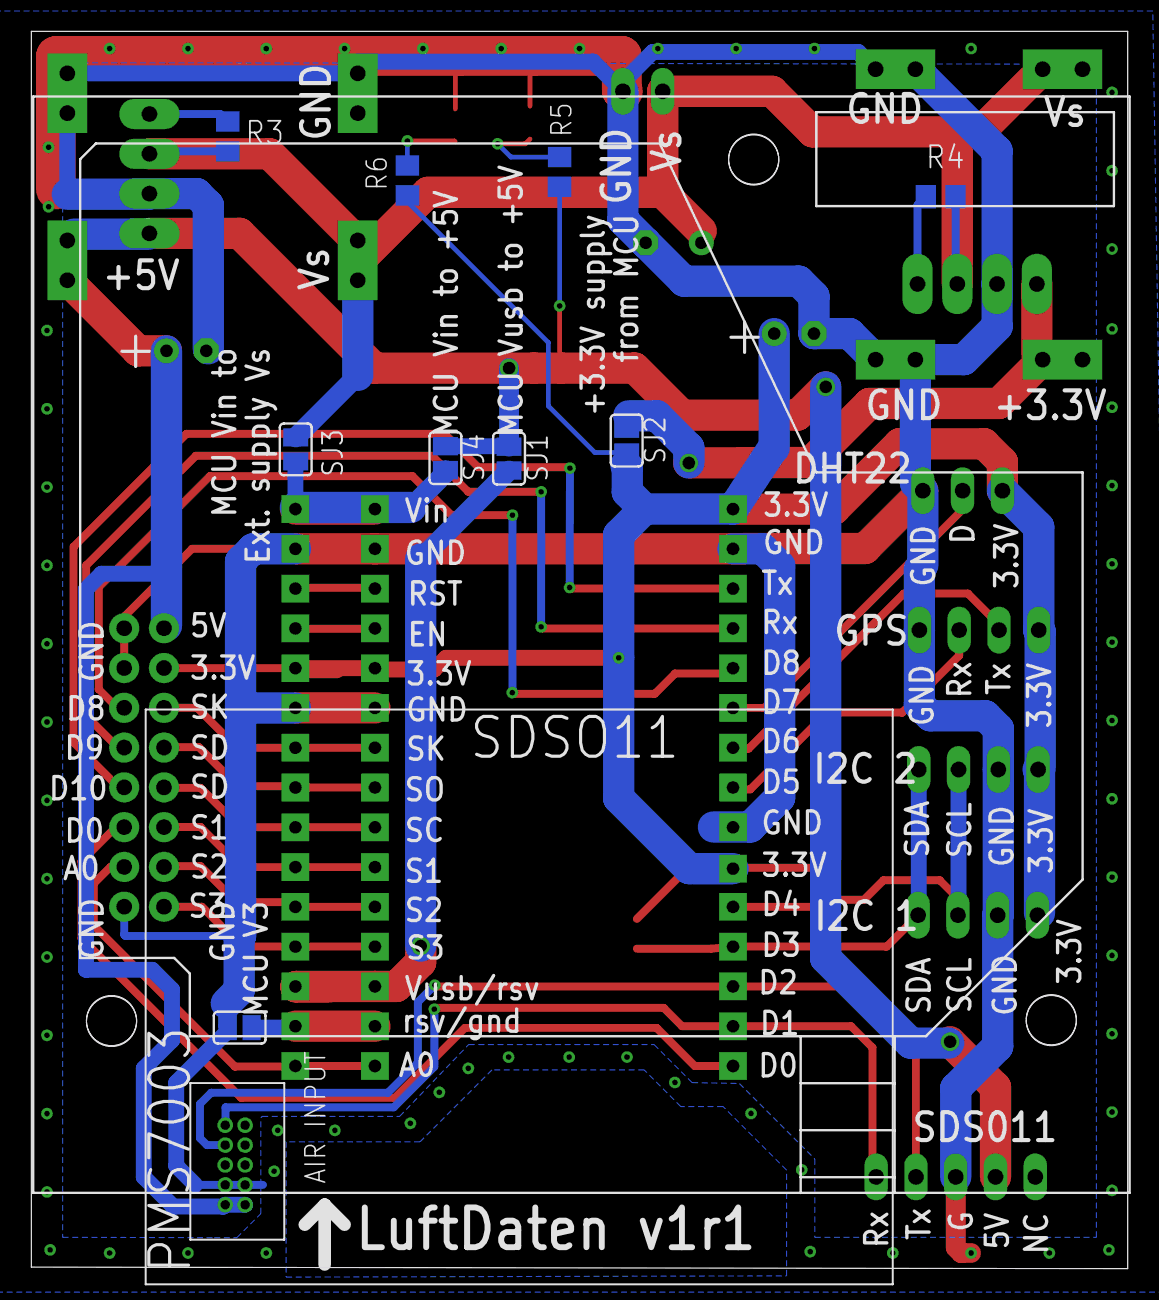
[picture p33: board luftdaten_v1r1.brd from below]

Board: 2 copper layers, 70.0 x 79.0 mm, 30 parts (11 on the bottom side), 30 nets.

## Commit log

2020-04-28 update sensor image
2021-10-12 Update README.md
    Change Luftdaten references to Sensor Community
